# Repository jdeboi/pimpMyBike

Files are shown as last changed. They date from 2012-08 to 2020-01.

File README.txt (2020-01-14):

UPDATED: 5/2015

16x16 Matrix - 
Turning indicators/strobe light for a 16x16 LED Matrix (2, 8x16 Adafruit LED Backpacks). Includes a Processing visualizer for designing custom blinky patterns.

16x24 Matrix (original, 2012) - 
Original Arduino sketch for the bike circuit containing LED turn indicators, brake light, speedometer, and odometer. Also includes a Processing LED visualizer for designing custom light patterns.

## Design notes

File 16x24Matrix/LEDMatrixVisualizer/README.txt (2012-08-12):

Jenna deBoisblanc
July, 2012
Shout out to Adafruit Industries

This LED Visualizer makes it easy to design patterns for use with the 16x24 Red LED Matrix Panel - Chainable HT1632C Driver, which is produced by Adafruit Industries and is available here: 
https://www.adafruit.com/products/555.

Download the entire LEDMatrixVisualizer folder and open LEDMatrixVisualizer in Processing.

Once your design is complete, you can export the pixel values to a text file, or you can import previous designs (edit the file paths at the top of the sketch). The print button allows you to generate a bitmap of the LED values (either 1 or 
0). If you're using the Arduino bike circuit code, you can copy/paste the LED values into the brake light or turning indicator LED pixel arrays.

All of the shapes are stored in linked lists.  At some point, it'd be nice to write functions to animate individual shape objects.

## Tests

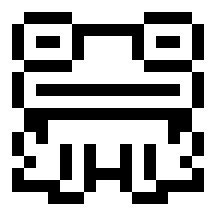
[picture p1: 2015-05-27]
16x16Matrix/LEDMatrixVisualizer16x16/images/testing.jpg

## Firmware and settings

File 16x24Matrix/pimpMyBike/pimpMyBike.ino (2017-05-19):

////////////////////////////////////////////////////////////////////////
// pimpMyBike ///////////////////////////////////
// jdeboi
// September 15, 2012
// For more information: www.jdeboi.com
// Feel free to copy, distribute, improve, deconstruct...
////////////////////////////////////////////////////////////////////////

////////////////////////////////////
///////Headers/libraries//////////////////////
///////////////////////////////

#include <avr/pgmspace.h>
#include <stdlib.h>
#include <LiquidCrystal.h>
#include <Wire.h>
#include "Timer.h"            //https://github.com/JChristensen/Timer
#include "HT1632.h"           //https://github.com/adafruit/HT1632

///////////////////////////////////////////////////////////////
////////////////////////VARIABLES////////////////////
///////////////////////////////////////////

////////////////////////////////////
/////Variables to set/////////////////////////
///////////////////////////////

//set metric = false to use miles
boolean metric = true;
//wheel circumference in centimeters 
float wheelC = 212.5;


////////////////////////////////////
///////Pins to set////////////////////////////
///////////////////////////////

/*
Note: Change the pin numbers according
to your individual circuit. For most pins, 
it doesn't matter whether you use analog 
or digital I/O.
*/

const int brakeVPin = A0;   //analog input
const int reedPin = A1;     //any input
const int turnRPin = A3;    //any input; pin used to sense turning button
const int turnRLED = A5;    //any output; pin used to turn on button LED
const int turnLPin = A2;    //any input; pin used to sense turning button
const int turnLLED = A4;    //any output; pin used to turn on button LED
const int data = 11;        //any output; LED panel, orange wire
const int wr = 12;          //any output; LED panel, yellow wire
const int cs = 10;          //any output; LED panel, white wire
const int LCD4 = 2;         //any output; LCD pin #4
const int LCD6 = 3;         //any output; LCD pin #6    
const int LCD11 = 13;       //any output; LCD pin #11
const int LCD12 = 8;        //any output; LCD pin #12
const int LCD13 = 7;        //any output; LCD pin #13 
const int LCD14 = 4;        //any output; LCD pin #14
const int redLCD = 5;       //analog out (~PWM pin); LCD pin #16  
const int greenLCD = 6;     //analog out (~PWM pin); LCD pin #17
const int blueLCD = 9;      //analog out (~PWM pin); LCD pin #18 

/*
for LCD pin wiring: http://learn.adafruit.com/character-lcds/rgb-backlit-lcds

LCD# - Arduino#
-------------------
1 - GND
2 - 5V
3 - LCD potentiometer (not connected to Arduino)
4 - LCD1 (I used pin D2)
5 - GND
6 - LCD2 (I used pin D3)
7 through 10 aren't connected to the Arduino
11 - LCD3 
12 - LCD4 
13 - LCD5 
14 - LCD6 
15 - 5V
16 - redLCD, ~PWM pin (I used pin D5)
17 - greenLCD, ~PWM pin (I used pin D6)
18 - blueLCD, ~PWM pin (I used pin D9)

16 through 18 control the color of the LCD backlight
*/


////////////////////////////////////
///////Bike Variables/////////////////////////
///////////////////////////////

///////Brake Switch/////////////
int brakeV; 
int brakeOld; 
int brakeThresh = 250;
int brakeTime;
boolean brakeOn = false;
boolean strobeOn = false;

///////Reed Switch//////////////
int circleNum = 0;
float odometer = 0;
float miles = 0;
float kilometers = 0;
float speedometer = 0;
float MPH = 0;
float KPH = 0;
int reedTime = 0;
int reedTimeDelta = 0;
boolean reedOn = false;

////Turning Indicator Buttons///
boolean rOn = false;
boolean lOn = false;
boolean stateChange = false;
boolean turningOn = false;
boolean turningLOn = false;
boolean turningROn = false;
int right;
int left;
int rightOld;
int leftOld;
unsigned long millisRight;
unsigned long millisLeft;

//////LED Panel/////////////////
//single matrix
int numMatrices = 1;
int height = 16;
int width = numMatrices * 32;
int numLEDs = height*width;
int stepSize = 2;
char pixel;
HT1632LEDMatrix matrix = HT1632LEDMatrix(data, wr, cs);

///////LCD//////////////////////
LiquidCrystal lcd(LCD4, LCD6, LCD11, LCD12, LCD13, LCD14);
int LCDButton;
int brightness = 50;
int red = 130;
int green = 222;
int blue = 219;
int counter;
boolean brightUp;
boolean backlightOn; 

//////////Timer Variables///////
int blinkTime = 1000;
Timer scrollTimer;
int scrollTime = 130;
Timer strobeTimer;
int strobeTime = 100;
boolean blinkOn;

////////////////////////////////////
/////////LED Designs//////////////////////////
///////////////////////////////

/*
Note: bitmap of LED pixels (ints in 
binary store value of each LED- either
1 or 0- on/off respectively.
printed  the ints using LED matrix visulaizer
http://jdeboi.com/portfolio/electronics/bike/visualizer.html

save SRAM by saving in flash memory:
http://arduino.cc/en/Reference/PROGMEM
not enough SRAM to store LED patterns as
ints or chars
*/

//right turning indicator LED pattern
const unsigned char rightBytes[48] PROGMEM  = {
  28, 0, 56, 
  14, 0, 112, 
  7, 0, 224, 
  3, 129, 192, 
  1, 195, 128, 
  0, 231, 0, 
  0, 126, 0, 
  0, 60, 0, 
  28, 0, 56, 
  14, 0, 112, 
  7, 0, 224, 
  3, 129, 192, 
  1, 195, 128, 
  0, 231, 0, 
  0, 126, 0, 
  0, 60, 0
};

//left turning indicator LED pattern
const unsigned char leftBytes [48] PROGMEM = {
  0, 24, 0, 
  0, 60, 0, 
  0, 126, 0, 
  0, 231, 0, 
  1, 195, 128, 
  3, 129, 192, 
  7, 0, 224, 
  14, 0, 112, 
  0, 28, 0, 
  0, 62, 0, 
  0, 119, 0, 
  0, 227, 128, 
  1, 193, 192, 
  3, 128, 224, 
  7, 0, 112, 
  14, 0, 56
};

//brake and night-taillight LED pattern
const unsigned char brakeBytes [48] PROGMEM = {
  0, 24, 0, 
  0, 60, 0, 
  0, 126, 0, 
  0, 231, 0, 
  1, 195, 128, 
  3, 153, 192, 
  7, 60, 224, 
  14, 126, 112, 
  14, 126, 112, 
  7, 60, 224, 
  3, 153, 192, 
  1, 195, 128, 
  0, 231, 0, 
  0, 126, 0, 
  0, 60, 0, 
  0, 24, 0
};

//byte array to store LED pattern;
//needed for translate()
byte tmpByteLEDs [48] = {
  0, 0, 0, 
  0, 0, 0, 
  0, 0, 0, 
  0, 0, 0, 
  0, 0, 0, 
  0, 0, 0, 
  0, 0, 0, 
  0, 0, 0, 
  0, 0, 0, 
  0, 0, 0, 
  0, 0, 0, 
  0, 0, 0, 
  0, 0, 0, 
  0, 0, 0, 
  0, 0, 0, 
  0, 0, 0
};



///////////////////////////////////////////////////////////////
//////////////////////////SETUP//////////////////////
///////////////////////////////////////////

void setup() {
  delay(500);
  // set up the LCD's number of rows and columns:
  scrollTimer.every(scrollTime, scroll);
  strobeTimer.every(strobeTime, strobe);
  lcd.begin(16, 2);
  backlightOff();

  matrix.begin(HT1632_COMMON_16NMOS); 
  delay(500);
  matrix.fillScreen();
  delay(500);
  matrix.clearScreen();

  pinMode(turnRPin, INPUT); 
  pinMode(turnRLED, OUTPUT);   
  pinMode(turnLPin, INPUT);
  pinMode(turnLLED, OUTPUT);
  
  /*
  measure the brake threshold when the Arduino turns on- 
  the tab may have moved around since the last time
  you used the bike circuit
  */
  brakeThresh = analogRead(brakeV) - 25;
  delay(800);

  /*
  optional to do: Map the brake LED brightness
  to force applied on the brakes,
  more accurately, to the voltage divider of two
  resistors in series- 
  map(0, 1023, 0, brakeThresh);
  */
}

///////////////////////////////////////////////////////////////
////////////////////////////LOOP/////////////////////
///////////////////////////////////////////

void loop() {
  checkBraking();
  checkTurning();
  setTurning();
  scrollTimer.update();
  strobeTimer.update();
  checkReed();
  printSpeed();
  printDistance();
  //debugBrake();
}

///////////////////////////////////////////////////////////////
///////////////////////////CHECK/////////////////////
///////////////////////////////////////////

void checkBraking(){
  brakeV = analogRead(brakeVPin);
  if(brakeV < brakeThresh){
    brakeOn = true;
    drawBrake();
  }
  else if (brakeV > brakeThresh){
    if(brakeOn == true){
      brakeOn = false;
      stateChange = true;
      setTurning();
    }
  }
}

void checkTurning(){
  stateChange = false;
  right = digitalRead(turnRPin);
  left = digitalRead(turnLPin);
  if(right == HIGH && rightOld == LOW){
    millisRight = millis();
    rOn =! rOn;
    stateChange = true;
  }
  else if(left == HIGH && leftOld == LOW){
    millisLeft = millis();
    lOn =! lOn;
    stateChange = true;
  }
  else if(right == HIGH && rightOld == HIGH){
    int deltaTime = millis() - millisRight;
    if(deltaTime > 1000 && !backlightOn){
      setLCDColor();  
    }
    else if (deltaTime > 1000) {
       backlightOff();
    }
  }
   else if(right == LOW && rightOld == HIGH){
    int deltaTime = millis() - millisRight;
    if(deltaTime > 1000){
      backlightOn =! backlightOn;
      delay(30);
    }  
  }
  else if(left == HIGH && leftOld == HIGH){
    if(millis() - millisLeft > 1000){
      resetLCD();
    }
  }
  rightOld = right;
  leftOld = left;
}

void checkReed(){
  int r = digitalRead(reedPin);
  if(r == 1 && reedOn == false){
    reedOn = true;
    reedTimeDelta = millis() - reedTime;
    reedTime = millis();
    circleNum++;
  }
  else if (r == 0 && reedOn){
    reedOn = false;
  }
}

///////////////////////////////////////////////////////////////
////////////////////////////SET//////////////////////
///////////////////////////////////////////

void setBrake(){
  for(int i = 0; i < 16; i++) {
    for(int j = 0; j < 3; j++) {
      tmpByteLEDs[i*3 + j] = pgm_read_byte_near(brakeBytes + i*3 + j);
    }
  }    
}

void setRight(){
  for(int i = 0; i < 16; i++) {
    for(int j = 0; j < 3; j++) {
      tmpByteLEDs[i*3 + j] = pgm_read_byte_near(rightBytes + i*3 + j);
    }
  }    
}

void setLeft(){
  for(int i = 0; i < 16; i++) {
    for(int j = 0; j < 3; j++) {
      tmpByteLEDs[i*3 + j] = pgm_read_byte_near(leftBytes + i*3 + j);
    }
  }    
}

void setTurning(){
  if(stateChange && brakeOn == false){  
    if(rOn && lOn){
      strobeOn =! strobeOn;
      if(strobeOn){
        drawBrake();
      }
      else{
        matrix.clearScreen();
      }
      delay(50);
      rOn = false;
      lOn = false;
      digitalWrite(turnRLED, LOW);
      digitalWrite(turnLLED, LOW);
      turningOn = false;
      turningROn = false;
      turningLOn = false;
    }
    else if(rOn && lOn == false){
      drawRight();
      digitalWrite(turnRLED, HIGH);
      turningOn = true;
      turningROn = true;
    }
    else if(rOn == false && lOn){
      drawLeft();
      digitalWrite(turnLLED, HIGH);
      turningOn = true;
      turningLOn = true;
    }
    else if(rOn == false && lOn == false){
      matrix.clearScreen();
      digitalWrite(turnRLED, LOW);
      digitalWrite(turnLLED, LOW);
      turningOn = false;
      turningROn = false;
      turningLOn = false;
    }
  }
}

void setBacklight() {
  /*
  courtesy of Adafruit
  http://learn.adafruit.com/character-lcds/rgb-backlit-lcds
  */
  
  // normalize the red LED - its brighter than the rest!
  int r = red;
  int g = green;
  int b = blue;

  r = map(r, 0, 255, 0, 100);
  g = map(g, 0, 255, 0, 150);
 
  r = map(r, 0, 255, 0, brightness);
  g = map(g, 0, 255, 0, brightness);
  b = map(b, 0, 255, 0, brightness);


  // common anode so invert!
  r = map(r, 0, 255, 255, 0);
  g = map(g, 0, 255, 255, 0);
  b = map(b, 0, 255, 255, 0);

  analogWrite(redLCD, r);
  analogWrite(greenLCD, g);
  analogWrite(blueLCD, b);
}

void backlightOff(){
  //common annode, so invert (?) 255 and 0
  analogWrite(redLCD, 255);
  analogWrite(greenLCD, 255);
  analogWrite(blueLCD, 255);
}

void setLCDColor(){
  counter++;
  if(counter == 765){
    counter = 0;
  }
  if(counter < 255){
    red = counter;
    green = 0;
    blue = 255 - counter;
  }
  else if(counter >= 255 && counter < 510) {
    red = 255 - (counter % 255);
    green = (counter % 255);
    blue = 0;
  }
  else {
    red = 0;
    green = 255 - (counter % 510);
    blue = counter % 510;
  }
  setBacklight();
  delay(5);
}

void resetLCD(){
  circleNum = 0;
  backlightOff();
}

///////////////////////////////////////////////////////////////
///////////////////////////PRINT/////////////////////
///////////////////////////////////////////

void printSpeed(){
  speedometer = wheelC/reedTimeDelta; 
  if(metric){
    KPH = speedometer * 36;
    lcd.setCursor(1, 0); 
    lcd.print("KPH: ");
    lcd.setCursor(6, 0);
    lcd.print(KPH, 2);
  }
  else{
    MPH = speedometer * 22.369;
    lcd.setCursor(1, 0); 
    lcd.print("MPH: ");
    lcd.setCursor(6, 0);
    lcd.print(MPH, 2);
  } 
}

void printDistance(){
  odometer = wheelC*circleNum;
  if(metric){
    kilometers = odometer / 100000;
    lcd.setCursor(1, 1); 
    lcd.print("KM: ");
    lcd.setCursor(5, 1);
    lcd.print(kilometers, 2); 
  }
  else{
    miles = odometer / 160934.4;
    lcd.setCursor(1, 1); 
    lcd.print("Miles: ");
    lcd.setCursor(5, 1);
    lcd.print(miles, 2); 
  }
}

///////////////////////////////////////////////////////////////
///////////////////////////DRAW//////////////////////
///////////////////////////////////////////

void drawLEDs(){
  for(int i = 0; i < 16; i++) {
    for(int j = 0; j < 3; j++) {
      for(int k = 0; k < 8; k++) {
        int pixel = bitRead(tmpByteLEDs[i*3+j], 7 - k);
        matrix.drawPixel(j*8+k, i, pixel);
      }
    }    
  }
  matrix.writeScreen();
}

void drawRight(){
  setRight();
  drawLEDs();
}

void drawLeft(){
  setLeft();
  drawLEDs();
}

void drawBrake(){
  setBrake();
  drawLEDs();
}

///////////////////////////////////////////////////////////////
/////////////////////////TRANSLATE///////////////////
///////////////////////////////////////////

void translate(int x, int y) {
  //x and y are # of steps in each dimension
  if (x > 0) {
    for (int i = 0; i < x; i++) {
      stepRight();
    }
  }
  else if (x < 0){  
    for (int i = 0; i > x; i--) {
      stepLeft();
    }
  }
  if (y > 0){
    for (int i = 0; i < y; i++) {
      stepUp();
    }
  }
  else if (y < 0){
    for (int i = 0; i > y; i--) {
      stepDown();
    }
  }
  drawLEDs();
}

void stepLeft(){
  //move pixels to the left one bit at a time
  //by setting each bit equal to the bit on the right
  for(int i = 0; i < 16; i++) {
    byte b1t = tmpByteLEDs[i*3] << 1;
    byte b2t = tmpByteLEDs[i*3 + 1] << 1;
    byte b3t = tmpByteLEDs[i*3 + 2] << 1;
    bitWrite(b1t, 0, bitRead(tmpByteLEDs[i*3 + 1], 7));
    bitWrite(b2t, 0, bitRead(tmpByteLEDs[i*3 + 2], 7));
    bitWrite(b3t, 0, bitRead(tmpByteLEDs[i*3], 7));
    tmpByteLEDs[i*3] = b1t;
    tmpByteLEDs[i*3 + 1] = b2t;
    tmpByteLEDs[i*3 + 2] = b3t;
  }
}

void stepRight(){
  //move pixels to the right one bit at a time
  //by setting each bit equal to the bit on the left
  for(int i = 0; i < 16; i++) {
    byte b1t = tmpByteLEDs[i*3] >> 1;
    byte b2t = tmpByteLEDs[i*3 + 1] >> 1;
    byte b3t = tmpByteLEDs[i*3 + 2] >> 1;
    bitWrite(b1t, 7, bitRead(tmpByteLEDs[i*3 + 1], 0));
    bitWrite(b2t, 7, bitRead(tmpByteLEDs[i*3 + 2], 0));
    bitWrite(b3t, 7, bitRead(tmpByteLEDs[i*3], 0));
    tmpByteLEDs[i*3] = b1t;
    tmpByteLEDs[i*3 + 1] = b2t;
    tmpByteLEDs[i*3 + 2] = b3t;
  }
}

void stepUp(){
  //move pixels up by setting each byte equal to the byte 
  //below it
  byte b1t =  tmpByteLEDs[0];
  byte b2t = tmpByteLEDs[1];
  byte b3t = tmpByteLEDs[2];
  for(int i = 0; i < 15; i++) {
    for (int j = 0; j < 3; j++){
      tmpByteLEDs[i*3 + j] = tmpByteLEDs[(i+1)*3 + j];
    }
  }
  tmpByteLEDs[45] = b1t;
  tmpByteLEDs[46] = b2t;
  tmpByteLEDs[47] = b3t;
}

void stepDown(){
  //move pixels down by setting each byte equal to the byte 
  //above it
  byte b1t =  tmpByteLEDs[45];
  byte b2t = tmpByteLEDs[46];
  byte b3t = tmpByteLEDs[47];
  for(int i = 15; i > 0; i--) {
    for (int j = 0; j < 3; j++){
      tmpByteLEDs[i*3 + j] = tmpByteLEDs[(i-1)*3 + j];
    }
  }
  tmpByteLEDs[0] = b1t;
  tmpByteLEDs[1] = b2t;
  tmpByteLEDs[2] = b3t;
}


///////////////////////////////////////////////////////////////
//////////////////////TIMER FUNCTIONS////////////////
///////////////////////////////////////////

void scroll(){
  if(brakeOn == false){
    if(rOn){
      translate(0, -1);
    }
    else if(lOn){
      translate(0, 1);
    }
  }
}

void strobe(){
  if(strobeOn && turningOn == false && brakeOn == false){
    blinkOn =! blinkOn;
    if(blinkOn){
      drawBrake();
    }
    else{
      matrix.clearScreen();
    }
  }
}

///////////////////////////////////////////////////////////////
//////////////////////DEBUG FUNCTIONS////////////////
///////////////////////////////////////////

void debugBrake(){
  int br = analogRead(brakeVPin);
  lcd.setCursor(1, 0); 
  lcd.print(br);
}

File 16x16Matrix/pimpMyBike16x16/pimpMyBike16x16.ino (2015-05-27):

#include <Wire.h>
#include "Adafruit_16x16matrix.h"
#include "Adafruit_GFX.h"

Adafruit_16x16matrix matrix = Adafruit_16x16matrix();
int buttonLED1 = 4;
int buttonLED2 = 5;
int buttonPin1 = 2;
int buttonPin2 = 3;
int scrollDelay = 50;
int blinkTime = 200;
double lastTime = 0;

boolean blinkOn = false;
boolean leftOn = false;
boolean rightOn = false;
boolean ledsOn = false;

static const uint8_t PROGMEM
  blinky_bmp[] = { 
    B11111000, B00011111, 
    B11100110, B01100111, 
    B11001111, B11110011, 
    B10000110, B01100001, 
    B10001100, B00110001, 
    B01111110, B01111110, 
    B01110011, B11001110, 
    B01100001, B10000110, 
    B00110011, B11001100, 
    B00011111, B11111000, 
    B00100000, B00000100, 
    B10001101, B10110001, 
    B11011101, B10111011, 
    B11011111, B11111011, 
    B11101111, B11110111, 
    B11110000, B00001111
};

void setup() {
  Serial.begin(9600);
  Serial.println("16x16 LED Matrix Test");
  pinMode(buttonLED1, OUTPUT);
  pinMode(buttonLED2, OUTPUT); 
  pinMode(buttonPin1, INPUT_PULLUP); 
  pinMode(buttonPin2, INPUT_PULLUP); 
  
  matrix.begin(0x71, 0x70);  // pass in the addresses
  matrix.setBrightness(3);
  blinkyOff();
}

void loop() {
  
  checkButtons();
  loopBlinky();
  
  // CUSTOM BLINKY b/c of timing
  // interrupt turning or blinky if there's a change
  
}

void checkButtons() {
  setButtonState();
  setButtons();
}

void setButtons() {
  if(leftOn && rightOn) {
    digitalWrite(buttonLED1, HIGH);
    digitalWrite(buttonLED2, HIGH);
    blinkOn = true;
  }
  else if (leftOn && !rightOn) {
    digitalWrite(buttonLED1, HIGH);
    digitalWrite(buttonLED2, LOW);
    leftArrow();
  }
  else if (!leftOn && rightOn) {
    digitalWrite(buttonLED1, LOW);
    digitalWrite(buttonLED2, HIGH);
    rightArrow();
  }
  else {
    matrix.clear();
    matrix.writeDisplay();
    resetButtons();
  }
}

boolean checkChangeState() {
  if(leftOn == digitalRead(buttonPin1) || rightOn == digitalRead(buttonPin2)) return true;
  return false;
}

void setButtonState() {
  if(leftOn == digitalRead(buttonPin1)) {
    delay(1);
    leftOn = !digitalRead(buttonPin1);
  }
  else if (rightOn == digitalRead(buttonPin2)) {
    delay(1);
    rightOn = !digitalRead(buttonPin2);
  }
}

void resetButtons() {
  digitalWrite(buttonLED1, LOW);
  digitalWrite(buttonLED2, LOW);
  blinkOn = false;
}

/*
void checkButtons() {
  if(!digitalRead(buttonPin1) && !digitalRead(buttonPin2)) {
    if(!blinkyOn) {
      blinkyOn();
    }
  }
  else if(!digitalRead(buttonPin1)) {
    digitalWrite(buttonLED1, HIGH);
    leftArrow();
  }
  else if(!digitalRead(buttonPin2)) {
    digitalWrite(buttonLED2, HIGH);
    rightArrow();
  }
  else {
    digitalWrite(buttonLED1, LOW);
    digitalWrite(buttonLED2, LOW);    
    matrix.clear();
    matrix.writeDisplay();
    if(blinkyOn) {
      blinkyOff();
    }
  }
}
*/
    
void leftArrow() {
  matrix.setTextSize(2);
  matrix.setTextWrap(false);  
  matrix.setTextColor(LED_ON);
  for (int8_t x=0; x>=-24; x--) {
    matrix.clear();
    if(checkChangeState()) break;
    matrix.setCursor(x,1);
    matrix.print("<<<<");
    matrix.writeDisplay();
    
    delay(scrollDelay);
  }
}

void rightArrow() {
  matrix.setTextSize(2);
  matrix.setTextWrap(false);  
  matrix.setTextColor(LED_ON);
  for (int8_t x=-24; x<=0; x++) {
    if(checkChangeState()) break;
    matrix.clear();
    matrix.setCursor(x,1);
    matrix.print(">>>>");
    matrix.writeDisplay();
    delay(scrollDelay);
  }
}

void blinkyOn() {
  //matrix.blinkRate(1);
  matrix.clear();
  matrix.drawBitmap(0, 0, blinky_bmp, 16, 16, LED_ON);
  matrix.writeDisplay();
}

void blinkyOff() {
  //matrix.blinkRate(0);
  matrix.clear();
  matrix.writeDisplay();
  blinkOn = false;
}

void loopBlinky() {
  if(blinkOn) {
    if(millis() - lastTime > blinkTime) {
      lastTime = millis();
      ledsOn = !ledsOn;
      if(ledsOn) blinkyOn();
      else blinkyOff();
    }
  }
}

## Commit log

2012-07-15 LED visualizer
    [bike.fzz]
2012-07-20 HT1632 (LED matrix lots of edits)
2012-07-23 export/ import frames
2012-07-23 finished LED visualizer
2012-07-26 fixes chapes; dynamic fill
    [LEDCircle.pde, LEDLine.pde, LEDMatrixVisualizer.pde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]
2012-08-11 lots of changes to LED visualizer
    [bike.fzz]
2012-08-12 fixed shapes on led sketch
    [ImageButtons.pde, LEDMatrixVisualizer.pde, LEDRect.pde]
2012-08-12 updated fritzing bike circuit diagram
    [bike.fzz]
2012-08-12 i think i'm done with the LED visualizer
2012-08-12 readme file for led visualizer
2012-08-12 editing bike circuit
2012-08-18 int[] to char[] for storing led values
2012-08-18 print char[]
2012-08-18 ugh can't get leds to work. must be a memory issue. meh
    [pimpMyBike.ino]
2012-08-19 made it easy to print LED values as an array of bytes
2012-08-20 byte leds?
2012-09-03 added button to adjust LCD color and brightness
2012-09-16 changed wheel circumference
2012-10-31 lcd pin explanation
2012-10-31 LCD pin better explain
2012-10-31 lcd pin update
2012-11-18 update lcd pin variables
2013-01-03 update fritzing
    [bike.fzz]
2017-05-19 fixing prog_uchar doesn't name a type error -- const unsigned char
    [pimpMyBike.ino]
